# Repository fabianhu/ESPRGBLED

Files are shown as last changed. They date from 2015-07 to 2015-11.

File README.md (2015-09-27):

# ESPRGBLED
RGB LED driver with 3 N-channel MOSFET drivers and an ESP8266

This is a small hardware board to drive a RGB LED or stripe with a ESP8266 ESP-12e module.

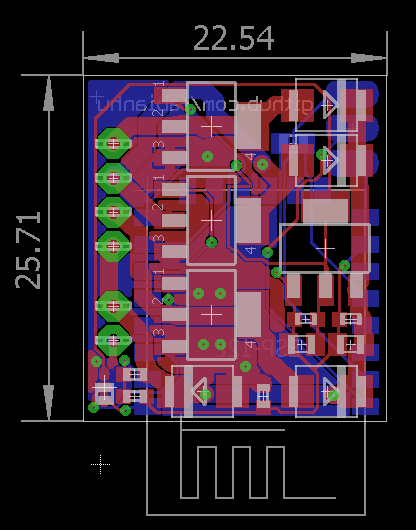
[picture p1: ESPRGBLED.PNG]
ESPRGBLED


The folder /ESP8266 contains a caller monitor script for the fritz box:
- lights red on incoming call
- green for connected
- blue for outgoing

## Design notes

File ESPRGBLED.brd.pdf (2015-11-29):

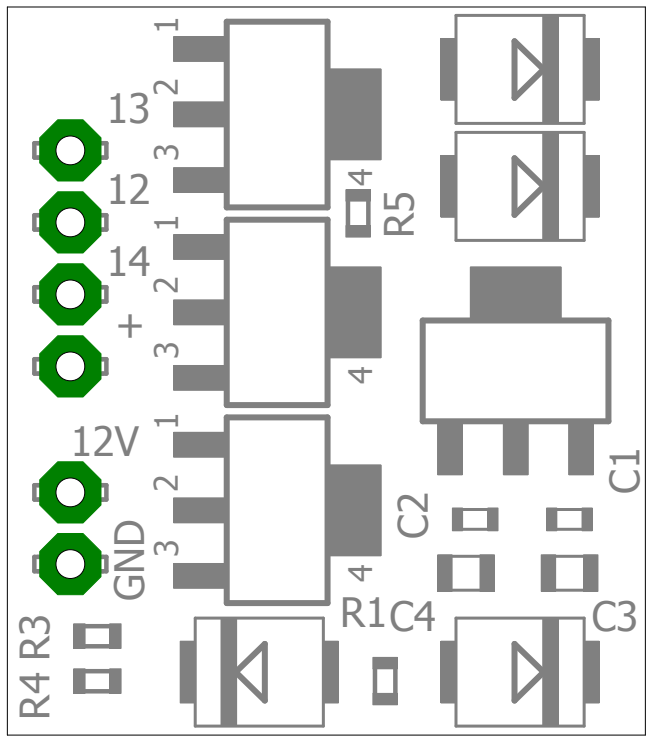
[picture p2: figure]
12VGND

10.08.2015 00:15 f=4.00 C:\Users\Fabi\Desktop\ESPRGBLED.brd

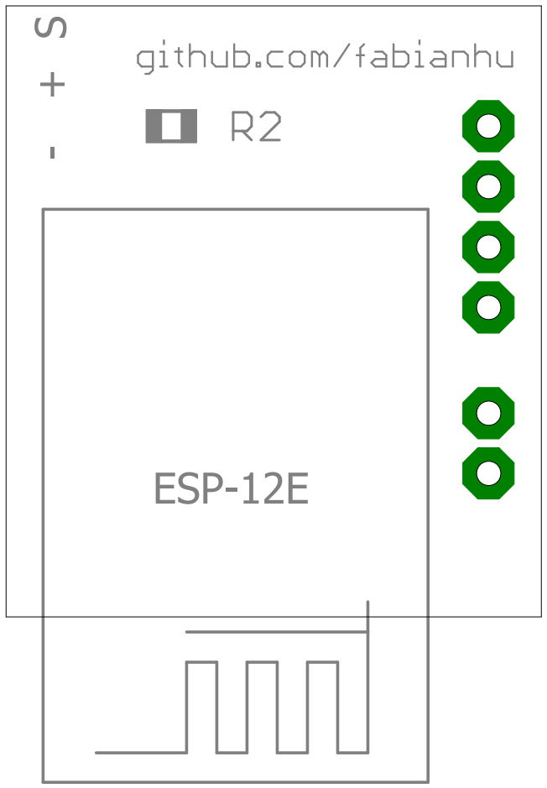
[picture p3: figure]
ESP-12E

10.08.2015 00:17 f=4.00 mirrored C:\Users\Fabi\Desktop\ESPRGBLED.brd

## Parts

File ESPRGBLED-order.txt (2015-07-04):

Order list for D:/projekt/work/#Github/ESPRGBLED/ESPRGBLED.sch
Exported from EAGLE with DesignLink

Anzahl	Value	Package	Ordercode	Hersteller	Herstellercode	Verfügbarkeit	Preis (ab)	Beschreibung
2		C0603K	1833863	AVX	0603YC104K4T4A	36637	0.0053	AVX - 0603YC104K4T4A - KONDENSATOR, MLCC, X7R, 100NF, 16V, 0603
2		C0805K	2332797	AVX	08055C224KAZ2A	4280	0.0601	AVX - 08055C224KAZ2A - KONDENSATOR, MLCC, X7R, 220NF, 50V, 0805
4	MBRS130LT3	SMB	2125539	ON SEMICONDUCTOR	MBRS130LT3G	1654	0.079	ON SEMICONDUCTOR - MBRS130LT3G - SCHOTTKY RECTIFIER, 2A, 30V, 403A
3		SOT223	1471058	FAIRCHILD SEMICONDUCTOR	FDT439N	2649	0.843	FAIRCHILD SEMICONDUCTOR - FDT439N - MOSFET, N-KANAL, SMD, SOT-223
1	0R	R0603	2467553	BOURNS	CR0603-J/-000ELF	24995	0.0027	BOURNS - CR0603-J/-000ELF - WIDERSTAND, 0R, 0.1W, 5%, 0603
1	10k	R0603	2078915RL	WELWYN	ASC0603-10KFT5	68788	0.0053	WELWYN - ASC0603-10KFT5 - WIDERSTAND, SCHWEFELRES., 10K, 0.1W, 1%
1	LM1117	SOT223	1202826	STMICROELECTRONICS	LD1117S33TR	34553	0.165	STMICROELECTRONICS - LD1117S33TR - LDO-SPANN.REGLER 3.3V SMD 1117 SOT-223-3
1	ESP8266	ESP-03	unknown					
1		3-WIRE_CONN	unknown					
6	CON1	CON1HP	unknown

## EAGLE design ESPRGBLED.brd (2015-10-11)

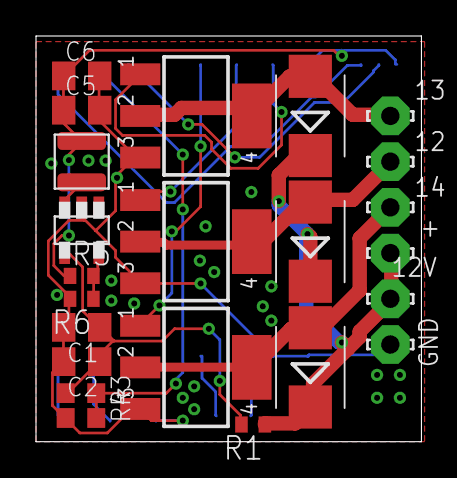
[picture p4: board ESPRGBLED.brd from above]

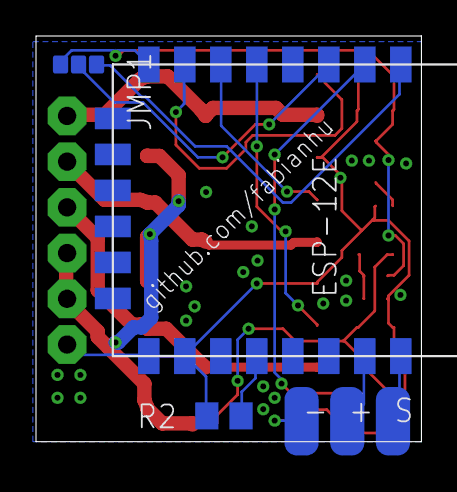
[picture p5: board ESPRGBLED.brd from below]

Board: 2 copper layers, 21.4 x 22.5 mm, 27 parts (4 on the bottom side), 18 nets.

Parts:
12, 12V, 13, 14: LSP10
+: LSP10
C1, C2, C5, C6: 10uF; C0805K
GND: LSP10
JMP1: 0R-JUMPC; C0R-JMP
L1: L_10UH_560MA; TYS3010100M-10
MDL1: ESP8266-ESP12E
PWR1:D1, PWR2:D1, PWR3:D1: MBRS130LT3; SMB
PWR1:T1, PWR2:T1, PWR3:T1: SOT223
R1: 0R; R0402
R2: 0R; R0805
R3: 100k; R0603
R4: 10k; R0603
R5: 61k9; R0402
R6: 20k; R0402
U$2: TPS560200; SOT23-5
U$3: 3-WIRE_CONN

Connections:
+12V: 12V.MP, +.MP, PWR1:D1.C, PWR2:D1.C, PWR3:D1.C, R1.1
ADC: MDL1.2, R3.1, R4.2
CH_PD: JMP1.2, MDL1.3
GND: C1.2, C2.2, C5.2, C6.2, GND.MP, MDL1.9, MDL1.10, PWR1:T1.3, PWR2:T1.3, PWR3:T1.3, R2.2, R4.1, R6.2, U$2.2, U$3.0V
GPIO0: MDL1.12, R2.1
GPIO12: MDL1.6, PWR2:T1.1
GPIO13: MDL1.7, PWR1:T1.1
GPIO14: MDL1.5, PWR3:T1.1
unnamed: 13.MP, PWR1:D1.A, PWR1:T1.2, PWR1:T1.4
unnamed: 12.MP, PWR2:D1.A, PWR2:T1.2, PWR2:T1.4
unnamed: 14.MP, PWR3:D1.A, PWR3:T1.2, PWR3:T1.4
unnamed: MDL1.16, U$3.SIG
unnamed: MDL1.15, U$3.5V
unnamed: L1.P$1, U$2.3
unnamed: R5.2, R6.1, U$2.5
REST: JMP1.1, MDL1.1
VCC: C5.1, C6.1, JMP1.3, L1.P$2, MDL1.8, R5.1
VIN: C1.1, C2.1, R1.2, R3.2, U$2.4

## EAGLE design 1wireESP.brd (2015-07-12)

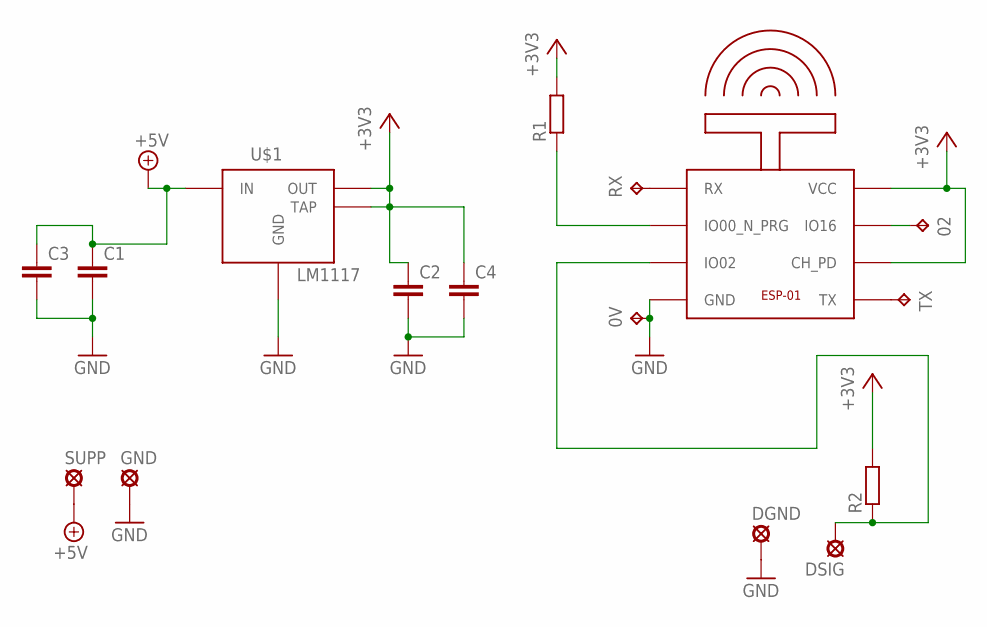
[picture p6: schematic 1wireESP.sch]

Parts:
0V, 02: TPB2,54; B2,54
C1, C2: C-EUC0603K; C0603K
C3, C4: C-EUC0805K; C0805K
DGND: LSP10
DSIG: LSP10
GND: LSP10
R1, R2: R-EU_R0603; R0603
RX: TPB2,54; B2,54
SUPP: LSP10
TX: TPB2,54; B2,54
U$1: LM1117; SOT223
U$2: ESP-01

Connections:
+3V3: C2.1, C4.1, R1.2, R2.2, U$1.MID (OUT), U$1.TAP, U$2.CH_PD, U$2.VCC
+5V: C1.1, C3.1, SUPP.MP, U$1.RIGHT (IN)
GND: 0V.TP, C1.2, C2.2, C3.2, C4.2, DGND.MP, GND.MP, U$1.LEFT (GND), U$2.GND
unnamed: R1.1, U$2.GPIO0_N_PROG (IO00_N_PRG)
unnamed: 02.TP, U$2.GPIO16 (IO16)
unnamed: DSIG.MP, R2.1, U$2.GPIO02 (IO02)
unnamed: TX.TP, U$2.TX
unnamed: RX.TP, U$2.RX

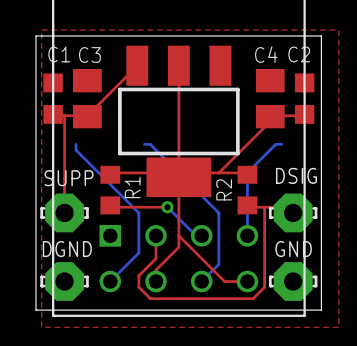
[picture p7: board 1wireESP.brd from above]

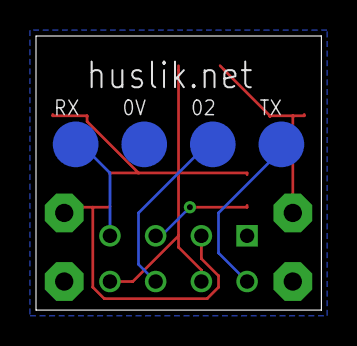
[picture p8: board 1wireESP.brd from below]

Board: 2 copper layers, 15.9 x 15.2 mm, 16 parts (4 on the bottom side), 8 nets.

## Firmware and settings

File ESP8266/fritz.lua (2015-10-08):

-- activate server in fritz box by calling #96*5*
-- configure your wifi
-- wifi.setmode(wifi.STATION)
-- wifi.sta.config("SSID","password")
-- wifi.sta.autoconnect(1)

mode = 0
level_r=0
level_g=0
level_b=0

maxpwm = 100
steppwm = 10
interval = 1000

function split(s, delimiter)
    result = {};
    for match in (s..delimiter):gmatch("(.-)"..delimiter) do
        table.insert(result, match);
    end
    return result;
end

function setoff()
    pwm.setduty(6,0) -- r
    pwm.setduty(5,0) -- g
    pwm.setduty(7,0) -- b 
end

function setupfade()
    mode = 3
    level_r = maxpwm / 3 -- r
    level_g = maxpwm / 3*2 -- g
    level_b = 0 -- b  
end


function fritzrcv(sck, c) 
    print(c) 
    sps = split(c,';')
    for i,v in ipairs(sps) do
        print(v)
    end
    
    if sps[2] == "CALL" then
      mode = 0
      level_r = 0 -- r
      level_g = 0 -- g
      level_b = 1023 -- b  
    end
    
    if sps[2] == "RING" then
      mode = 1
      level_r = 1023 -- r
      level_g = 0 -- g
      level_b = 0 -- b  
    end
    
    if sps[2] == "CONNECT" then
      mode = 0
      level_r = 0 -- r
      level_g = 1023 -- g
      level_b = 0 -- b  
    end
    
    if sps[2] == "DISCONNECT" then
      mode = 0
      level_r = 0 -- r
      level_g = 0 -- g
      level_b = 0 -- b  
    end

end


function fritzconn(sck,c)
    print("connected to FB")
      mode = 0
      level_r = 0 -- r
      level_g = maxpwm -- g
      level_b = 0 -- b  
end

function fritzdisconn(sck,c)
    print("disconnection from FB")
    mode = 0
    level_r = 1023
	node.restart()
end

function pwmsetduty(pin,lvl)
    if lvl < 0 then 
        lvl = 0-lvl 
    end
  
    pwm.setduty(pin,lvl)
end

function setlight()
    pwmsetduty(6,level_r) -- r
    pwmsetduty(5,level_g) -- g
    pwmsetduty(7,level_b) -- b 
    --print (level_r, level_g, level_b )
end


function inc(n) -- with overflow
    if n < (maxpwm-steppwm) then
        return n+steppwm
    else
        return -maxpwm
    end
end

function dec(n)
    if n > steppwm then
        return n-steppwm
    else
        return 0
    end
end

function dolight()
    ip,nm,gw = wifi.sta.getip()
    if ip == nil then
        print("ough")
        tmr.alarm(1, 10000, 0, function() 
            node.restart()
        end)
	else
			tmr.stop(1)
	end
    
    if mode == 3 then -- cycle
        level_r = inc(level_r)
        level_g = inc(level_g)
        level_b = inc(level_b)
        setlight()
        return
    end
    
    if mode == 0 then -- static
        level_r = dec(level_r)
        level_g = dec(level_g)
        level_b = dec(level_b)
        setlight()
        return
    end

    if mode == 1 then -- blink
        setlight()
        tmr.alarm(3, interval/2 , 0, function() 
            setoff()
        end)
    end
   
end

pwm.setup(5,1000,0)
pwm.setup(6,1000,0)
pwm.setup(7,1000,0)

level_b = 500
setlight()

setoff()

-- wait for connect
tmr.alarm(1, 5000, 0, function() 
    ip,nm,gw = wifi.sta.getip()
    print(ip)
    if ip == nil then
        print "ough"
        tmr.alarm(1, 10000, 0, function() 
            node.restart()
        end)
    else
        pwm.setduty(5,0) -- g
        sk=net.createConnection(net.TCP, 0)
        sk:on("receive", fritzrcv )
        sk:on("connection", fritzconn )
        sk:on("reconnection", fritzconn )
        sk:on("disconnection", fritzdisconn )
        --sk:on("sent", fritzsent )
        
        sk:connect(1012,"192.168.1.1")
		tmr.alarm(2, interval, 1, dolight)
    end
end)

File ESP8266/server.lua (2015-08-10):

-- wifi.setmode(wifi.SOFTAP)
wifi.ap.config({ssid='WiFi Light 192.168.4.1'})
print(wifi.ap.getip())

pwm.setup(5,1000,0)
pwm.setup(6,1000,0)
pwm.setup(7,1000,0)

isOpen = false

-- A simple http server
if srv then
  srv:close()
end
srv = net.createServer(net.TCP)
srv:listen(80, function(conn)

  conn:on("receive", function(conn, payload)
    -- print(payload)
    local isOpen = false

    conn:on("sent", function(conn)
      if not isOpen then
        print('open')
        isOpen = true
        file.open(fileName, 'r')
      end
      local data = file.read(1024) -- 1024 max
      if data then
        print('send ' .. #data)
        conn:send(data)
      else
        print('close')
        file.close()
        conn:close()
        conn = nil
      end
    end)

    if string.sub(payload, 1, 6) == 'GET / ' then
      fileName = 'index.html'
      conn:send("HTTP/1.1 200 OK\r\n")
      conn:send("Content-type: text/html\r\n")
      conn:send("Connection: close\r\n\r\n")
    elseif string.sub(payload, 1, 9) == 'GET /off ' then
      conn:close()
      conn = nil
      pwm.setduty(5,0)
      pwm.setduty(6,0) 
      pwm.setduty(7,0)
    elseif string.sub(payload, 1, 6) == 'GET /~' then
      conn:close()
      conn = nil
      -- print(string.sub(payload, 6, 12))
      local r = tonumber(string.sub(payload, 7, 8), 16)
      local g = tonumber(string.sub(payload, 9, 10), 16)
      local b = tonumber(string.sub(payload, 11, 12), 16)

      pwm.setduty(5,g*4)
      pwm.setduty(6,r*4) 
      pwm.setduty(7,b*4)   

    else
      conn:close()
      --conn = nil
    end

  end)

end)

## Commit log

2015-06-21 initial stuff
    [ESPRGBLED.brd, ESPRGBLED.sch]
2015-06-23 added layout
    [ESPRGBLED.brd, ESPRGBLED.sch]
2015-07-04 updated layouts
    [1wireESP.brd, 1wireESP.sch, ESPRGBLED.brd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]
2015-07-12 through hole
    [ESPRGBLED.brd, ESPRGBLED.sch]
2015-07-12 minor stuff
    [ESPRGBLED.brd, ESPRGBLED.sch]
2015-07-18 updated HW with reset-wakeup option
    [ESPRGBLED.brd, ESPRGBLED.sch]
2015-08-02 updated BOM
    [ESPRGBLED.brd, ESPRGBLED.sch]
2015-08-06 minor layout stuff
    [ESPRGBLED.brd, ESPRGBLED.sch]
2015-08-10 first working over http
    [ESPRGBLED.brd, ESPRGBLED.sch]
2015-08-15 updated schematics with step down vreg
    [ESPRGBLED.brd, LM1117SW.brd, LM1117SW.sch]
2015-08-16 layout stuff
    [ESPRGBLED.brd, LM1117SW.brd, LM1117SW.sch]
2015-08-16 finished LM1117 replacement
    [LM1117SW.brd, LM1117SW.sch]
2015-08-16 updated order list
    [LM1117SW.brd, LM1117SW.sch]
2015-08-17 removed lm1117
    [LM1117SW.brd, LM1117SW.sch]
